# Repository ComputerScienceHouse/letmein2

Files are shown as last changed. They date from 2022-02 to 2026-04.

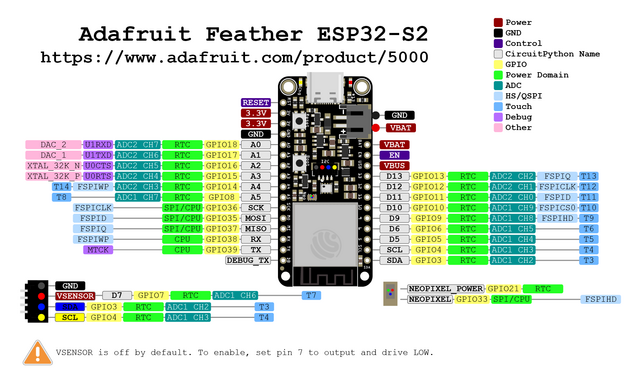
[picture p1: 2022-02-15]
adafruit_products_Adafruit_Feather_ESP32-S2_Pinout.png

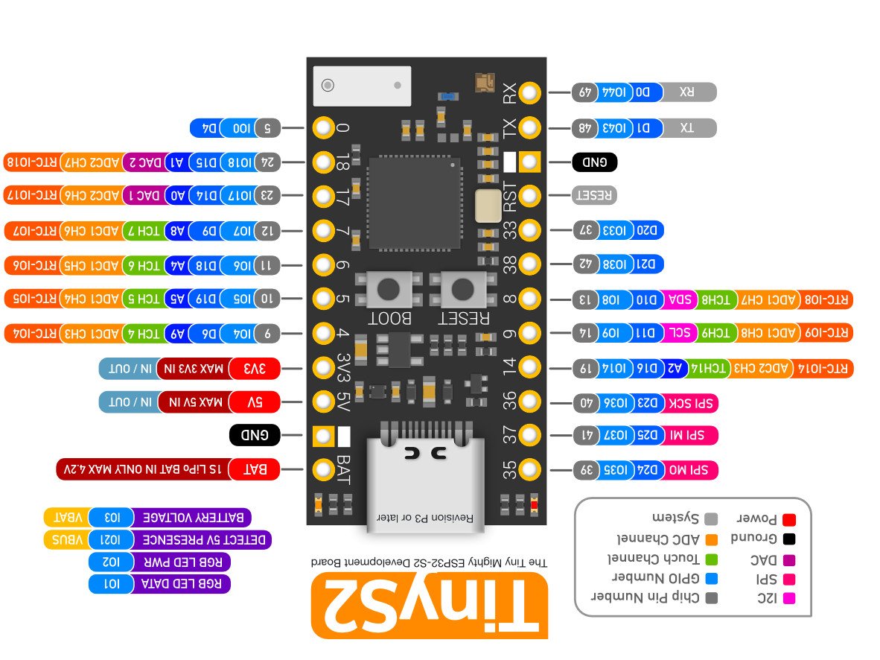
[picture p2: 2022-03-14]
TinyS2Pinout.jpg

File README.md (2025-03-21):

# LetMeIn v2 

<!-- <img src="https://csh.rit.edu/~wilnil/storage/of-ohioan-descent.svg" alt="ohio badge" height="30px"/>  -->

 

Original Project: https://github.com/nfatkhiyev/letMeIn/

LetMeIn2 is a completely new re-write of LetMeIn that focuses on scalability and maintainability, while keeping cost-per-unit as low as possible. Current development uses the [Tiny S2](https://www.adafruit.com/product/5029) to ~~reduce~~ increase costs.



## How it works

output

A user, let's say Alice, visits the website, she selects a floor. Her phone POSTs to the server specifying where she is. The server will send an MQTT message on the letmein2/req topic with Alice's location. This will cause all letmein devices on floor to light up and make noise, indicating Alice's location. There will also be a message with an action button sent in Slack, listening for any updates to the request. Alice's phone will redirect her to a waiting screen (/anybody_home) that does another POST request (could be a GET) that waits for the server to give her a 200 response. On the backend, two things could happen: One is that someone on floor could hit one of the buttons (or respond by pressing the button in Slack) and go get her. That causes another MQTT message on the letmein2/ack topic, which answer's Alice's phone with a 200 message, and she's notified that someone is coming for her. The other is that nobody is there to answer the box (or maybe they don't like Alice), and after a set amount of time, the server sends Alice's phone a 408 message, and will send out a timeout message on the letmein2/ack topic.

## Developing

### Terminology

**Server**: The LetMeIn2 server, presumably running in a container on OKD.

**Guest**: The person/device/browser trying to connect to the Server.

**Knock**: Noun/Verb. A request to be let in, or the act of making a request to be let in.

**Client**: The embedded device that subscribes to the `letmein2/req` topic and listens for when a Gurst knocks

### MQTT
To subscribe to the **Server** as a **Client**, use this:
`mosquitto_sub -h mqtt.csh.rit.edu -t letmein2/ack -t letmein2/req`

You could also set up an app like `MQTT Explorer` (Works on Mac and Linux. If you're using Windows, please stop.)

### Server
In production, the **Server** is deployed to OKD.

Check the `/site` directory for instructions on how to run the **Server**.

### Client
Check the `/embedded` directory for instructions on how to work on the **Clients**.

You can use a program like `minicom` to connect a serial console.

### Hardware (As of Prototype 3)

You'll need:

- 5x Through-hole LEDs, any color, I used green. (Something like [this](https://www.digikey.com/en/products/detail/parallax-inc/751-00005/7791465))
- 1x [E-Switch LS085R100F160C1A](https://www.digikey.com/en/products/detail/e-switch/LS085R100F160C1A/1628106) along with an arcade button
- 1x Pushbutton (like, one of those [smol bois](https://www.digikey.com/en/products/detail/sparkfun-electronics/PRT-14460/7915747))
- 1x [Piezo Buzzer](https://www.digikey.com/en/products/detail/db-unlimited/TP134005-1/9990672)
- 1x [Tiny S2](https://www.digikey.com/en/products/detail/adafruit-industries-llc/5029/14307381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)

For the LED connectors:
- 1x 10 2.54mm pitch Position Header
- 1x 10 2.54mm pitch Position Header (male)

_This connector sucks. You should only need six headers to make the thing work. I hooked five of them up to GND when I was young and reckless._

Optional:
- 5x 680 ohm resistors for the LEDs (if you need to dim them)

If you'd like to socket your TinyS2, use these:
- 1x [11 Position Header](https://www.digikey.com/en/products/detail/sullins-connector-solutions/PPTC111LFBN-RC/810150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)
- 1x [12 Position Header](https://www.digikey.com/en/products/detail/sullins-connector-solutions/PPTC121LFBN-RC/807231)

Connect the button switch to COM and NO so that when the switch is closed, the circuit is completed and the button press is registered.

## Web API

### `/`
Returns the homepage

### `/session_info` (obsolete)
Returns any relevant info that a client should be aware of. Currently only returns the current timeout period of the server.

### `/request/:location` (obsolete)
Prompts a server to publish a request for a particular door.

### `/nvm` (obsolete)
Cancels a request that a client sends to the server.
<!--See the MVP issue for more info on this.-->

### `/anybody_home/:location` (obsolete)
Awaits an answer to a request made via the `/request/:location` route.

### `/knock/socket/:location`
Prompts a server to set up a "KnockSession" (not a real thing) that publishes a request on the MQTT network and opens a websocket connection with the client

## MQTT API

### `letmein2/req`
A topic meant for sending requests to the LetMeIn network. The payload should be a location that is registered in the app. The app should have a `location_map` defined. That looks like this:

```Go
var location_map = map[string]string{
    "n_stairs": "North Side Stairwell",
    "s_stairs": "South Side Stairwell",
    "level_a":  "Level A Elevator Lobby",
    "level_1":  "Level 1 Elevator Lobby",
    "l_well":   "L Well",
}
```

So, for example, you could publish on topic `letmein2/req` with payload `level_1` to indicate to the devices that you're waiting to be let in on the NRH Level 1 Elevator Lobby. 

### `letmein2/ack`
A topic meant for letting **Clients** acknowledge a **Knock**. The payload should be the location/ID of the device acknowledging. These aren't in a database anywhere, but they ought to be.

Note the Slack location in the client map, this will be used to send dynamic messages in Slack when a **Knock** is received or modified.

```Go
var client_map = map[string]string {
    "usercenter": "User Center",
    "lounge": "Lounge",
    "luser": "Luser Center",
    "software": "Software Room",
    "server": "Server Room",
    "slack": "Slack"
}
```

For example, you could publish on `letmein2/ack` with payload `usercenter` to let a waiting **Guest** know that you've heard their **Knock** and are coming to let them in.

### `letmein2/nvm`
A topic for notifying all **Clients** that a **Knock** is being cancelled. The payload should be a location from the above `location_map`.

If you publish on topic `letmein2/nvm` with payload `s_stairs`, that indicates that any pending **Knock** originating from the South Side Stairwell should be ignored (and that **Clients** should turn their lights/sound off!)

## SLACK CLIENT

Upon receiving any of these requests, the server will also send a **Slack** message to a predefined channel in a Slack workspace. The message it sends will also have a **Rescue** button, which will allow you to send a `letmein/ack` back, completing the request. Basically an acknowledge button but for lazy people who don't want to go to the button itself. The message will also self-update when a) the knock is acknowledged, b) the knock is timed out, or c) the knock is cancelled.

### Setting up the bot
Ensure that the application is given the scope `connections:write`, and make sure it is added to the channel (`/invite <app_name>` or `@<app_name>`).

To set up 2 way messaging, you need to define a Request URL (`your_server_url/actions`) within your Slack bot's settings . You can find this setting at [App Homepage](https://api.slack.com/apps) >> Your_App >> Interactivity & Shortcuts (under Features) >> Interactivity >> Request URL. Make sure Interactivity is toggled 'On,' and that your request URL uses HTTPS. If you don't do this, the **Rescue** button does not do anything.

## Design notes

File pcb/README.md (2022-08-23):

This is the PCB for LetMeIn

## Rev A

letmein rev a

## The Pencil Sharpener

There's a jumper soldered to Pin 37 on the board that goes to the pencil sharpener.

White goes to negative, brown goes to positive.

pencil sharpener

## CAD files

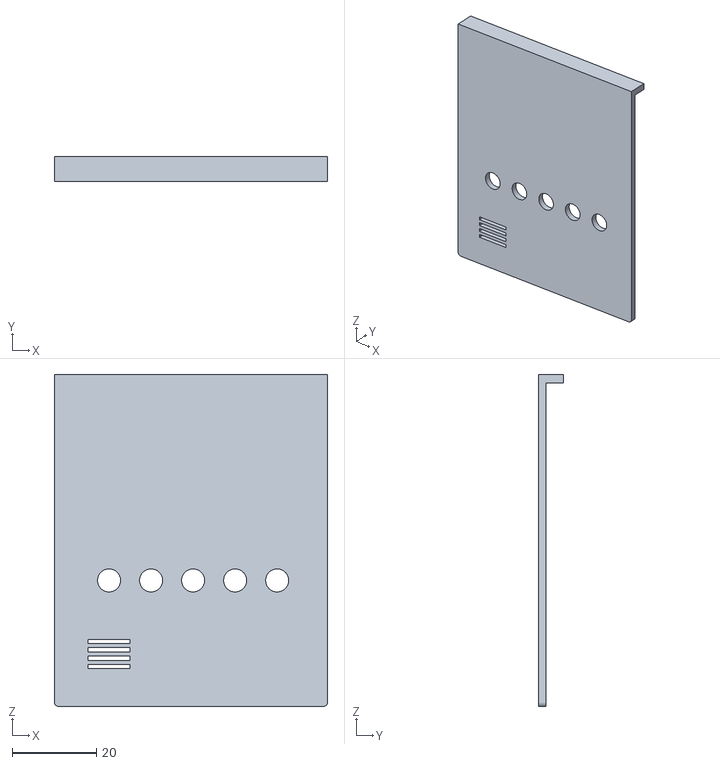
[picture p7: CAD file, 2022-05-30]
case/letmein_box-top_rev3.stl
65.0 x 6.00 x 79.0

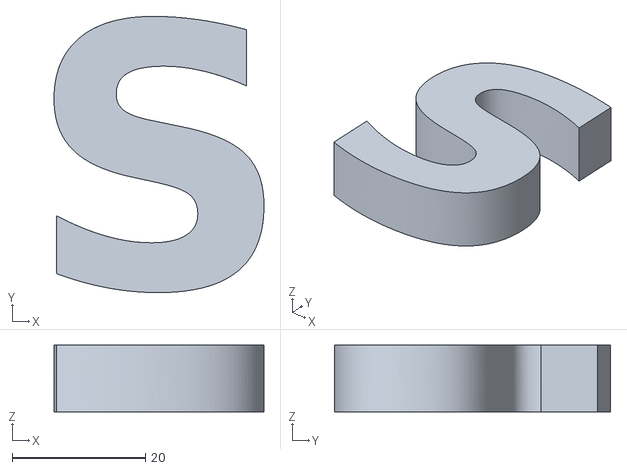
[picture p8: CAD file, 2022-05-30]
case/location_letters/Letter_S.stl
31.6 x 41.5 x 10.0

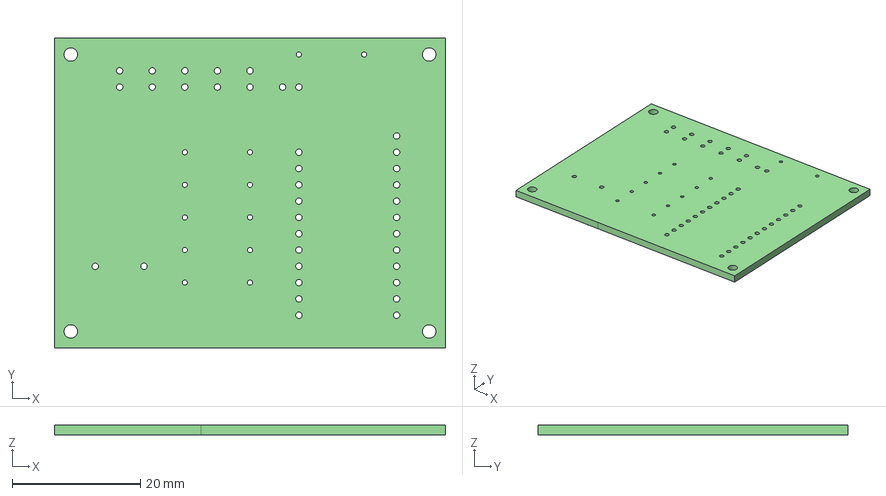
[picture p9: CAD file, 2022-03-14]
pcb/letmein.step
61.0 x 48.3 x 1.60 mm

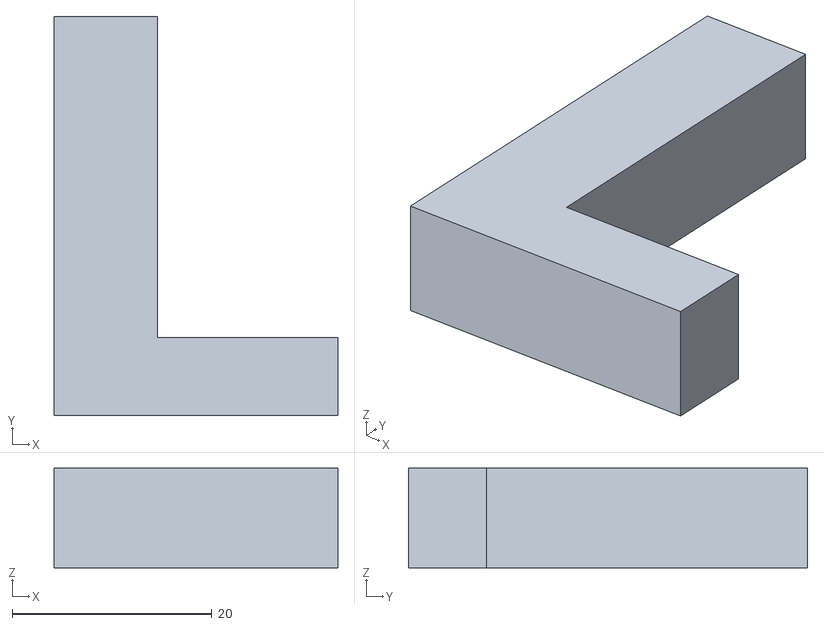
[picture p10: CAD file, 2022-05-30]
case/location_letters/Letter_L.stl
28.4 x 40.0 x 10.0

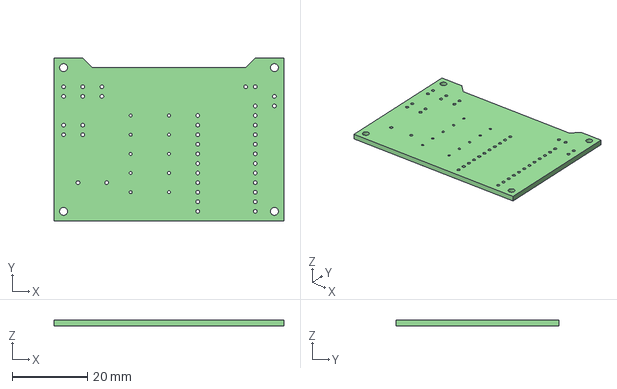
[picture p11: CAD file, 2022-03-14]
pcb/letmein_a2.step
61.0 x 43.2 x 1.60 mm

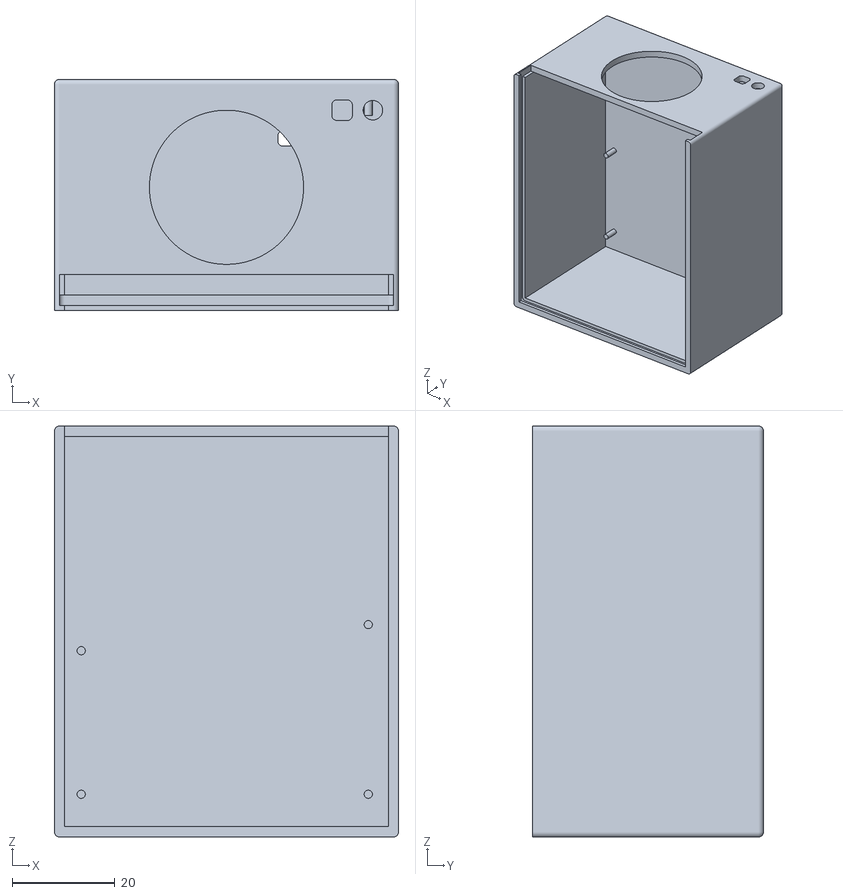
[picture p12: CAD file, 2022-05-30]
case/letmein_box-bottom_rev3.stl
67.0 x 45.0 x 80.0

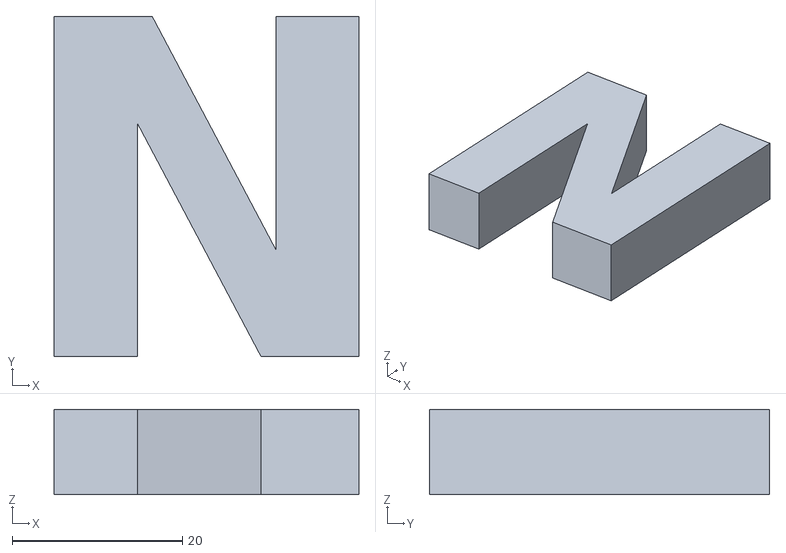
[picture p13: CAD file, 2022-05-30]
case/location_letters/Letter_N.stl
35.9 x 40.0 x 10.0

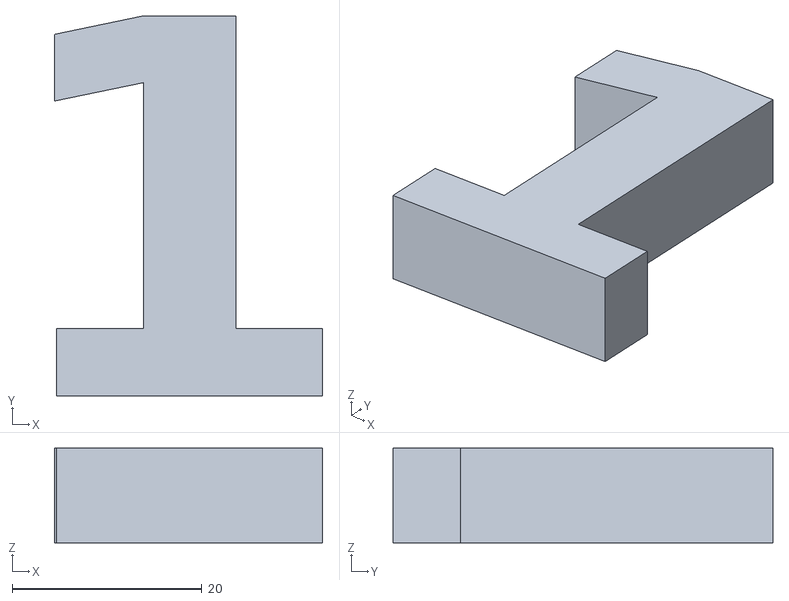
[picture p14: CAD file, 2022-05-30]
case/location_letters/one.stl
28.2 x 40.0 x 10.0

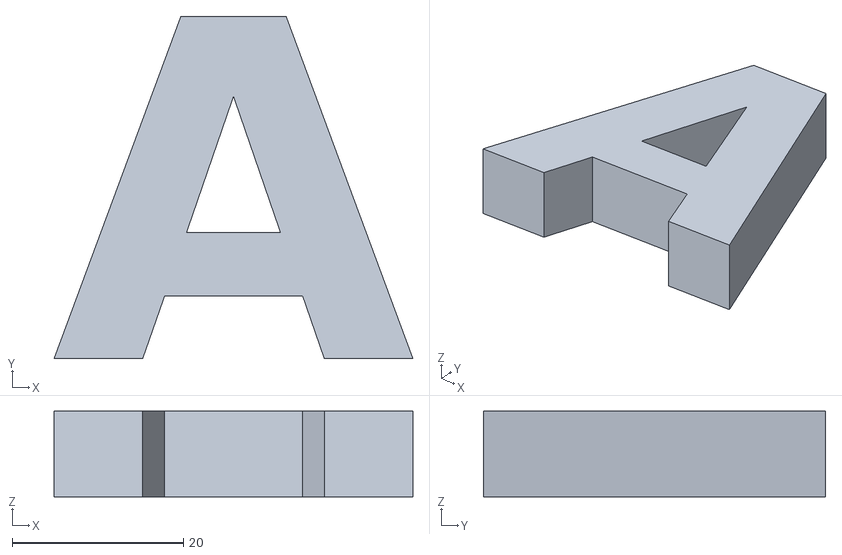
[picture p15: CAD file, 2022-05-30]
case/location_letters/Letter_A.stl
41.9 x 40.0 x 10.0

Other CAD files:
case/letmein_box.FCStd

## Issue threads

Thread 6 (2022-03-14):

`await asynccp.delay(seconds=0.1)` seems to delay for a full second?

WillNilges, 2022-03-14:
We're using https://github.com/WarriorOfWire/CircuitPython_async for async and for some reason it doesn't want to make delays any shorter than 1 second.

WillNilges, 2022-05-30:
https://learn.adafruit.com/cooperative-multitasking-in-circuitpython-with-asyncio

Adafruit has its own asyncio library. That might be a little more put-together.

WillNilges, 2022-08-18:
Fixed in #28

Closed 2022-08-18.

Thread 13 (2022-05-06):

Timeout is broken

WillNilges, 2022-05-06:
The client times out properly, but the website never gets updated.

WTF, this was working!?!??!

WillNilges, 2022-05-06:
It's also possible to ack a request even after it has timed out on the board.

WillNilges, 2022-05-07:
"Fixed" it in my `build` branch, I think.

WillNilges, 2022-05-10:
#17

WillNilges, 2022-05-10:
This issue still happens intermittently and I don't know why.

WillNilges, 2022-05-30:
I think this is fixed.

Closed 2022-05-30.

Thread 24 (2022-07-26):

Client Prototype 4

WillNilges, 2022-07-26:
A lotta shit needs to change lmaoooo

- [ ] Bigger speaker grille. Removing the front cover makes a _big_ difference in loudness
- [ ] Move buzzer as close to the front of the device as we can. Make it face outwards still
- [ ] Diffuse LEDs—OH MY GOD THEY ARE SO BRIGHT AAAAGH
- [ ] Fix PCB mounting posts
- [ ] Use Black filament
    - [ ] Sand the case so that labels and adhesive stick better?

WillNilges, 2022-08-29:
Related to #34

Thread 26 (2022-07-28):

UI Redesign

oliviaden, 2022-07-28:
Had some ideas for a new UI here's the link to the Figma whiteboard you can see the current and new redesigns.
[Figma link](https://www.figma.com/file/FHSujILREnE1wvtHjgmNhW/Let-me-in-UI-design?node-id=0%3A1)

Changes made were:
+ buttons have images of locations and are larger
+ button text weight is bolder and bigger
+ title "Welcome to Computer Science House" is bolder to show hierarchy
+ confirmation toast message
+ mobile formatting

Preview:
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

WillNilges, 2022-07-31:
I like the buttons, but I think the text ought to be big and white, and maybe have some kind of outline or drop shadow (if possible).

WillNilges, 2025-03-22:
I think a good place to start is to just make the UI more mobile friendly by fixing the tiny buttons. It's gonna take some fanagling, but it's really necessary given where it's most used.

Closed 2025-05-06.

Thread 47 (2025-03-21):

Letmein clients sometimes "die"

WillNilges, 2025-03-21:
Sometimes, the letmein clients will become unresponsive, with all LEDs lighting up. This can be fixed with a simple reboot.

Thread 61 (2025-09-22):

Mermaids

ErezBinyamin, 2025-09-22:
```mermaid
sequenceDiagram
    actor Alice
    participant Phone
    participant Server
    participant MQTT as "MQTT Broker"
    participant Devices as "Letmein Devices"
    participant Slack

    Alice ->> Phone: Visits website, selects floor
    Phone ->> Server: POST location (Alice's location)

    Server ->> MQTT: Publish letmein2/req (Alice's location)
    MQTT ->> Devices: Light up & make noise
    MQTT ->> Slack: Send message + action button

    Phone ->> Server: Redirect to /anybody_home (POST/GET)

    alt Someone responds (floor device or Slack)
        Devices ->> Server: Button pressed
        Slack ->> Server: Action button clicked
        Server ->> MQTT: Publish letmein2/ack
        Server -->> Phone: 200 OK ("someone coming")
    else Timeout / no response
        Server -->> Phone: 408 Timeout
        Server ->> MQTT: Publish letmein2/ack (timeout)
    end
```

This might be cool to add into the markdown...

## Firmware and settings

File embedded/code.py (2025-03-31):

import gc, os, board, tinys2, digitalio, wifi, socketpool, ssl
import adafruit_minimqtt.adafruit_minimqtt as MQTT
from secrets import *
from art import art_logo, art_mem_info
from jingles import Jingle
from app import App

def main():
    # Class for controlling the speaker and playing music
    jingle = Jingle(board.IO4)

    # Runs setup, then passes it off to loop()
    # Show signs of life
    art_logo()
    art_mem_info()
    jingle.boot_sync()
    
    # Set location of this device
    location = secrets["location"]
    if location == '':
        print('Location not set! Please set location.')
        exit(1)

    # WiFi
    print(f'Connecting to {secrets["ssid"]}')
    print('mac address:', "%02x:%02x:%02x:%02x:%02x:%02x" % tuple(map(int, wifi.radio.mac_address)))
    wifi.radio.connect(secrets['ssid'], secrets['password'])
    print(f'Connected to {secrets["ssid"]}!')
    pool = socketpool.SocketPool(wifi.radio) # Create a socket pool

    # Set up MQTT Client
    mqtt_client = MQTT.MQTT(
        broker=secrets["broker"],
        port=secrets["port"],
        socket_pool=pool,
        ssl_context=ssl.create_default_context(),
    )

    print("Attempting to connect to %s" % mqtt_client.broker)
    mqtt_client.connect()
    mqtt_client.subscribe(mqtt_req_topic)
    mqtt_client.subscribe(mqtt_ack_topic)
    mqtt_client.subscribe(mqtt_nvm_topic)
    mqtt_client.subscribe(mqtt_timeout_topic)

    app = App(mqtt_client, jingle)
    app.launch()

if __name__ == '__main__':
    main()

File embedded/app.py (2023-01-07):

import asyncio
from gpio import *
from secrets import *
from art import art_ready

class App:
    buffer = []
    def __init__(self, mqtt_client, jingle):
        self.mqtt_client = mqtt_client
        self.jingle = jingle
        self.stfu_counter = 0

        self.mqtt_client.on_message = self.message

    def launch(self):
        asyncio.run(self.run())

    async def run(self):
        # Jingle + ASCII art to let the user know the board is ready to go
        # Fancy :)
        sound_ready_task = asyncio.create_task(self.jingle.play("ready.jingle"))
        light_show_task = asyncio.create_task(light_show())
        await asyncio.gather(sound_ready_task, light_show_task)
        art_ready()
        check_ack_task = asyncio.create_task(self.check_ack())
        check_jingle_task = asyncio.create_task(self.check_jingle())
        check_mqtt_task = asyncio.create_task(self.check_mqtt())
        check_stfu_task = asyncio.create_task(self.check_stfu())
        stfu_decay_task = asyncio.create_task(self.stfu_decay())
        await asyncio.gather(
            check_ack_task,
            check_jingle_task,
            check_mqtt_task,
            check_stfu_task,
            stfu_decay_task
        )

    # Run MQTT transactions
    async def check_mqtt(self):
        while True:
            if self.jingle.buzzer.is_off():
                self.mqtt_client.loop()
            await asyncio.sleep(1)

    # See if the button is being pressed
    async def check_ack(self):
        while True:
            if ack.value:
                self.mqtt_client.publish(mqtt_ack_topic, f"{secrets['location']}")
                self.jingle.buzzer.off()
                all_off()
            await asyncio.sleep(0.5)

    async def check_stfu(self):
        while True:
            if stfu.value:
                if led_stfu.value:
                    self.stfu_counter = 0
                    self.mqtt_client.subscribe(mqtt_req_topic)
                else:
                    # Scale the counter to seconds (since the counter counts down once per second-ish)
                    # FIXME (willnilges): I think each tick is a bit longer than a second so keep that
                    # in mind when you're setting duration
                    self.stfu_counter = stfu_duration_minutes * 60
                    self.mqtt_client.unsubscribe(mqtt_req_topic)
                # We're gonna use the LED to keep track of the status b/c we're goblins.
                led_stfu.value = not led_stfu.value
            await asyncio.sleep(0.5)

    async def stfu_decay(self):
        while True:
            if led_stfu.value:
                if self.stfu_counter > 0:
                    self.stfu_counter -= 1
                    print(f"stfu_counter = {self.stfu_counter}")
                else:
                    led_stfu.value = 0
                    self.mqtt_client.subscribe(mqtt_req_topic)
            await asyncio.sleep(1)

    # Check if we should be playing music, and play music if so
    async def check_jingle(self):
        while True:
            if self.jingle.buzzer.is_off():
                # Probably has a bug: If one light is playing its jingle, then
                # another higher up on this list lights up, it'll switch songs
                # to the new light.
                if s_stairs.value:
                    await self.jingle.play(jingle_s_stairs)
                elif n_stairs.value:
                    await self.jingle.play(jingle_n_stairs)
                elif level_a.value:
                    await self.jingle.play(jingle_level_a)
                elif level_1.value:
                    await self.jingle.play(jingle_level_1)
                elif l_well.value:
                    await self.jingle.play(jingle_l_well)
                elif len(self.buffer):
                    first_item = self.buffer.pop(0)
                    if first_item == "timeout":
                        await self.jingle.play(jingle_timeout)
                    elif first_item == "ack":
                        await self.jingle.play(jingle_ack)
                    elif first_item == "nvm":
                        await self.jingle.play(jingle_nvm)
            await asyncio.sleep(1)

    # MQTT message handler
    def message(self, client, topic, message):
        # Method called when a client's subscribed feed has a new value.
        print("New message on topic {0}: {1}".format(topic, message))
        if topic == mqtt_req_topic:
            pencil.value = 1
            if message == "level_a":
                level_a.value = 1
            elif message == "level_1":
                level_1.value = 1
            elif message == "s_stairs":
                s_stairs.value = 1
            elif message == "n_stairs":
                n_stairs.value = 1
            elif message == "l_well":
                l_well.value = 1
        elif topic == mqtt_ack_topic:
            # FIXME (willnilges): The MQTT client is still subbed so it gets
            # messages and turns on the lights, but then it just turns right
            # back off. Should fix this. IDEA: Sub/Unsub.
            # TODO (willnilges): Perhaps a timeout topic would be nice.
            self.buffer.append("ack")
            all_off()
        elif topic == mqtt_timeout_topic:
            pencil.value = 0
            if "level_a" in message:
                level_a.value = 0
            elif "level_1" in message:
                level_1.value = 0
            elif "s_stairs" in message:
                s_stairs.value = 0
            elif "n_stairs" in message:
                n_stairs.value = 0
            elif "l_well" in message:
                l_well.value = 0
            self.buffer.append("timeout")
        elif topic == mqtt_nvm_topic:
            # TODO: Set up some kind of configurable dingus for this (and other)
            # location-based trees
            self.jingle.buzzer.off()
            pencil.value = 0
            if "level_a" in message:
                level_a.value = 0
            elif "level_1" in message:
                level_1.value = 0
            elif "s_stairs" in message:
                s_stairs.value = 0
            elif "n_stairs" in message:
                n_stairs.value = 0
            elif "l_well" in message:
                l_well.value = 0
            self.buffer.append("nvm")

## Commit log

2022-02-15 Fixed wifi. Dunno why that didn't work.
    [code.py]
2022-02-15 Add broker config files and minimqtt lib
    [code.py]
2022-03-06 YES I got a light to do the thing on the board
2022-03-06 Need to update page when button is pressed
2022-03-06 Got a basic timeout working — again
2022-03-07 Add code for L Well LED
2022-03-08 Tweak Dockerfile, Add KiCad dir, PIEZO BUZZER!!!!
    [letmein_pcb.kicad_pcb, letmein_pcb.kicad_sch]
2022-03-08 I made the MQTT work way better, but broke lights
    [code.py]
2022-03-08 Delete board
    Don't need it yet; Don't want it yet
    [letmein_pcb.kicad_pcb, letmein_pcb.kicad_sch]
2022-03-08 Break buzzer code out into its own file
    [buzzer.py, code.py]
2022-03-11 Remove resisor, update README
    There's still more components missing from this. Gonna hold off until I
    actually know what I need.
    [code.py]
2022-03-12 Add more components to README, add board, add case
    [letmein-B_Cu.gbr, letmein-B_Mask.gbr, letmein-B_Paste.gbr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]
2022-03-12 Shrink board, move headers
    [letmein-B_Cu.gbr, letmein-B_Mask.gbr, letmein-B_Paste.gbr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]
2022-03-12 Change LED connector style. WIP.
    I guess this is the start of Rev B. I realized that I could
    probably standardize the ribbon cable. In theory, I could also create a
    PCB for the front panel LEDs, then use a standard 2x5-pin ribbon cable
    to connect the two boards.
    Damn, that'd be a great idea.
    [letmein.kicad_pcb]
2022-03-14 Delete feather/lib directory
    Addresses #5. Still need to go see what I actually installed on my board though lmao
2022-05-06 Oh god I totally fucked up the CAD file
    I really ought to re-do it in a less stupid way.
    [Letter_A.stl, Letter_L.stl, Letter_N.stl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]
2022-05-06 Tweak case design
    Round out the holes, move 'em a bit
    [letmein_box-bottom_rev2.stl, letmein_box-top.stl, letmein_box-top_rev3.stl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]
2022-05-06 "Fix" timeout
    I no longer have any idea how this code works.
    Moved timeout c.String up to the acked case, and made "timeout" return
    false. This feels like it's going to shatter to pieces, but it works for
    now?
2022-05-06 Tweak case again, I guess
    [letmein_box.FCStd]
2022-05-10 Refactor buzzer. Jingles now extend buzzer.
    IDK if this is "good" per-se, but it feels less awkward to me.
    [buzzer.py, code.py, jingles.py]
2022-05-15 More freecad shit. I think this is prototype 2
    [letmein_box-bottom_rev3.stl, letmein_box.FCStd]
2022-05-16 First wack at a frontend
    Uses CSH Material theme!
2022-05-30 "Fix" the timeout animation
    Now the timer fills and empties properly (tm)
2022-05-30 Reduce ambiguity of directory names
    Rename 'feather' to 'embedded' and 'board' to 'pcb'
    [letmein-B_Cu.gbr, letmein-B_Mask.gbr, letmein-B_Paste.gbr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]
2022-06-23 Add picture of prototype
2022-07-24 Basic socket timeout works
2022-07-25 Test button seems to work. Time to try on device
2022-07-26 Add selective nvm (and nvm topic)
    Closes Issue #22. Now a client can send a `nvm` for specifically its
    location.
    [code.py]
2022-07-28 IDK how to make these buttons wrap
    I decided that I don't care for now lol
2022-07-28 Add an educational WebUI gif
    A demonstration of the Web UI
    TODO: Make funny video of person hitting the button
2022-08-18 Fix async or whatever on the Client (#28)
    * Remove some dead code
    * Add timeout topic
    * Fix imports
    I have cleaned up the code.
    By that, I mean I've shoved all those functions from "code" into their
    own file and made an object. I _feel_ like this will be less cursed and
    a little easier to read, but I could be totally wrong.
    Either way, it makes me feel better, so bite me.
    * Create Jingle Files
    * Dude, Song of Storms!
    * Allow comments in jingle files. They are NOT easy to parse when they're all together... Even less so when it's just a bunch of frequencies...
    * Song of healing go brrrr
    * STFU kinda works again, but not in minutes
    [app.py, buzzer.py, code.py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]
2022-08-23 Add pencil sharpener functionality
    It's on Pin 37 :)
2022-08-27 We are now at the point where pressing the Rescue button creates a thread that shows the user rescuing.
2022-09-06 Remove 'Rescue' button after trigger is resolved
2023-01-03 Added serial console guidelines
    Updated README for embedded to show how to access the serial console on the device via Mu or tio.
2025-03-21 Tell the truth about the TinyS2 (#45)
    The TinyS2 is ludicrously expensive and we should have just used an ESP32.
2025-03-23 Require name field to be non-empty; Implement name storage (#51)
    * added fallback for non-slack testing
    * require name input to be filled before allowing location selection
    * attempted to change mobile layout; not working currently
    * utilize cookies to retain previously inputted name field
    * attempted to change mobile layout; not working currently
    * revert broken ui changes
    * revert ui changes for real this time
    * adjust slack bot module to register bot validity rather than main function
    * changed env.bat to template file
    * update .gitignore to ignore env.bat
    * added required indicator for name input; fixed casing of slack logging.
    * removed test home html file
    * removed noisy lo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
2025-03-27 made the buttons bigger
2025-03-31 Reduce location button image file sizes (#53)
    * reduce location image file sizes
    * remove redundant css classes
2025-09-21 Switch to using localStorage instead of cookies
